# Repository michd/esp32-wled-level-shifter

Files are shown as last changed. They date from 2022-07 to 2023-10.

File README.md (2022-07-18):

# ESP32 WLED Level Shifter

A simple board to house an ESP32 dev board and a level shifter, so it can be hooked up directly to a powered 5V LED strip.

This fits a "ESP-32S Development Board", which can be found by plenty of sellers.

Designed for APA102 LEDs, so it has a CLK and DATA output.

Comes with a KiCad (6) board design and 3D-printable enclosure designed in FreeCAD.

See [Releases](https://github.com/michd/esp32-wled-level-shifter/releases) for exported PCB manufacturing files and STL files to 3D print.

## Images

The board; doesn't contain much.
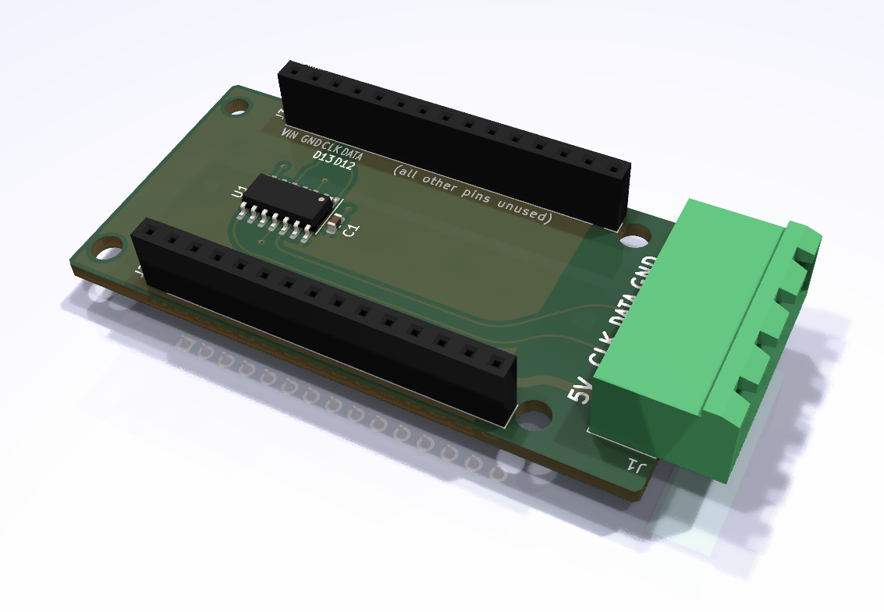
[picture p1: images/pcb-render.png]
3D render of circuit board showing generic socket pcb headers on either of the long sides, and a large 5.08mm 4 pin connector on one of the short ends


Bottom section of the 3D printed box
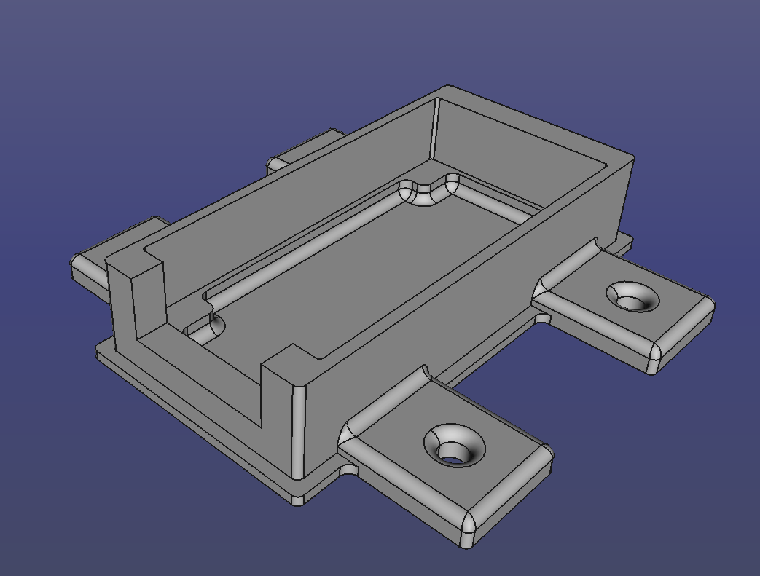
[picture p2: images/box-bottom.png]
Screenshot of FreeCAD showing the bottom of an enclosure. It's rectangular, has support for the circuit board to lay on, and a clearing in the front left wall for the connector. On both long sides, there are tabs with holes in them to fix the box to something with screws.


Top section of the 3D printed box
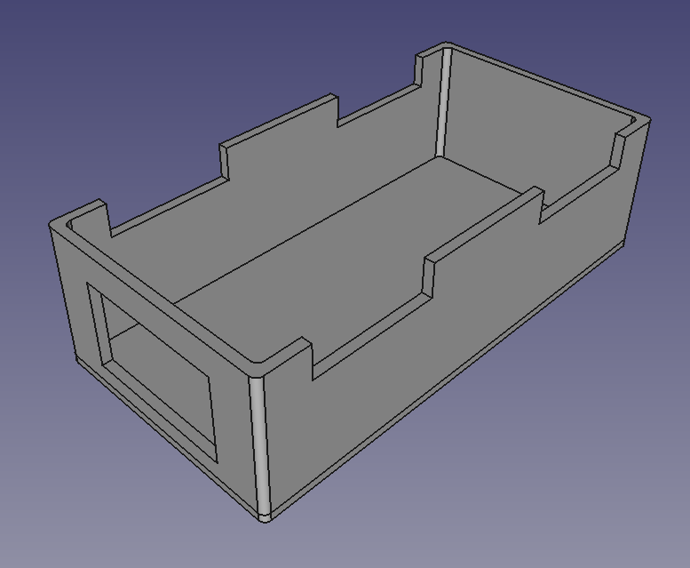
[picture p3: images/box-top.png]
Screenshot of FreeCAD showing the top of an enclosure (flipped upside down). It's rectangular with an open top, and has a clearing in the front left wall for the connector.


Assembled, in real life.
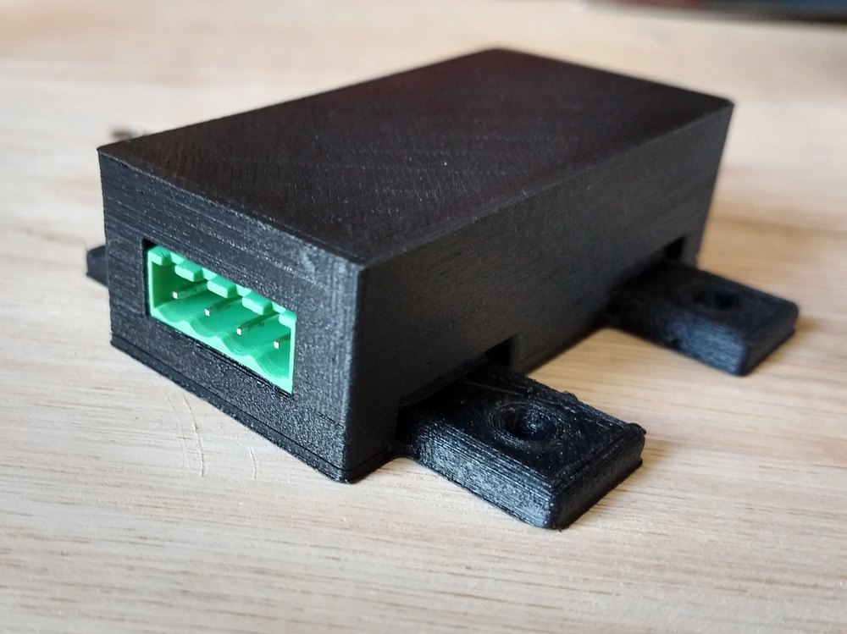
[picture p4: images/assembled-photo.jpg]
Photo of the assembled box. A black 3D printed box with the top and bottom put together (press-fit) is shown. In the clearing for the connector, you guessed it, there's the connector, flush with the edge of the enclosure.


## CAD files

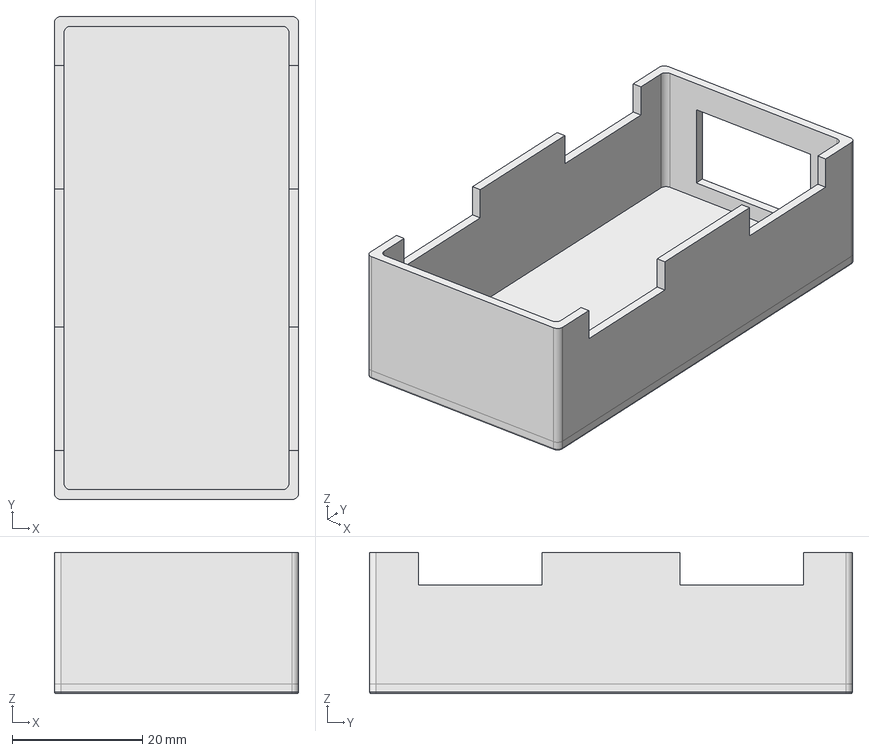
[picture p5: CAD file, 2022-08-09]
enclosure/esp32-wled-level-shifter-enclosure.FCStd
37.5 x 74.1 x 21.7 mm

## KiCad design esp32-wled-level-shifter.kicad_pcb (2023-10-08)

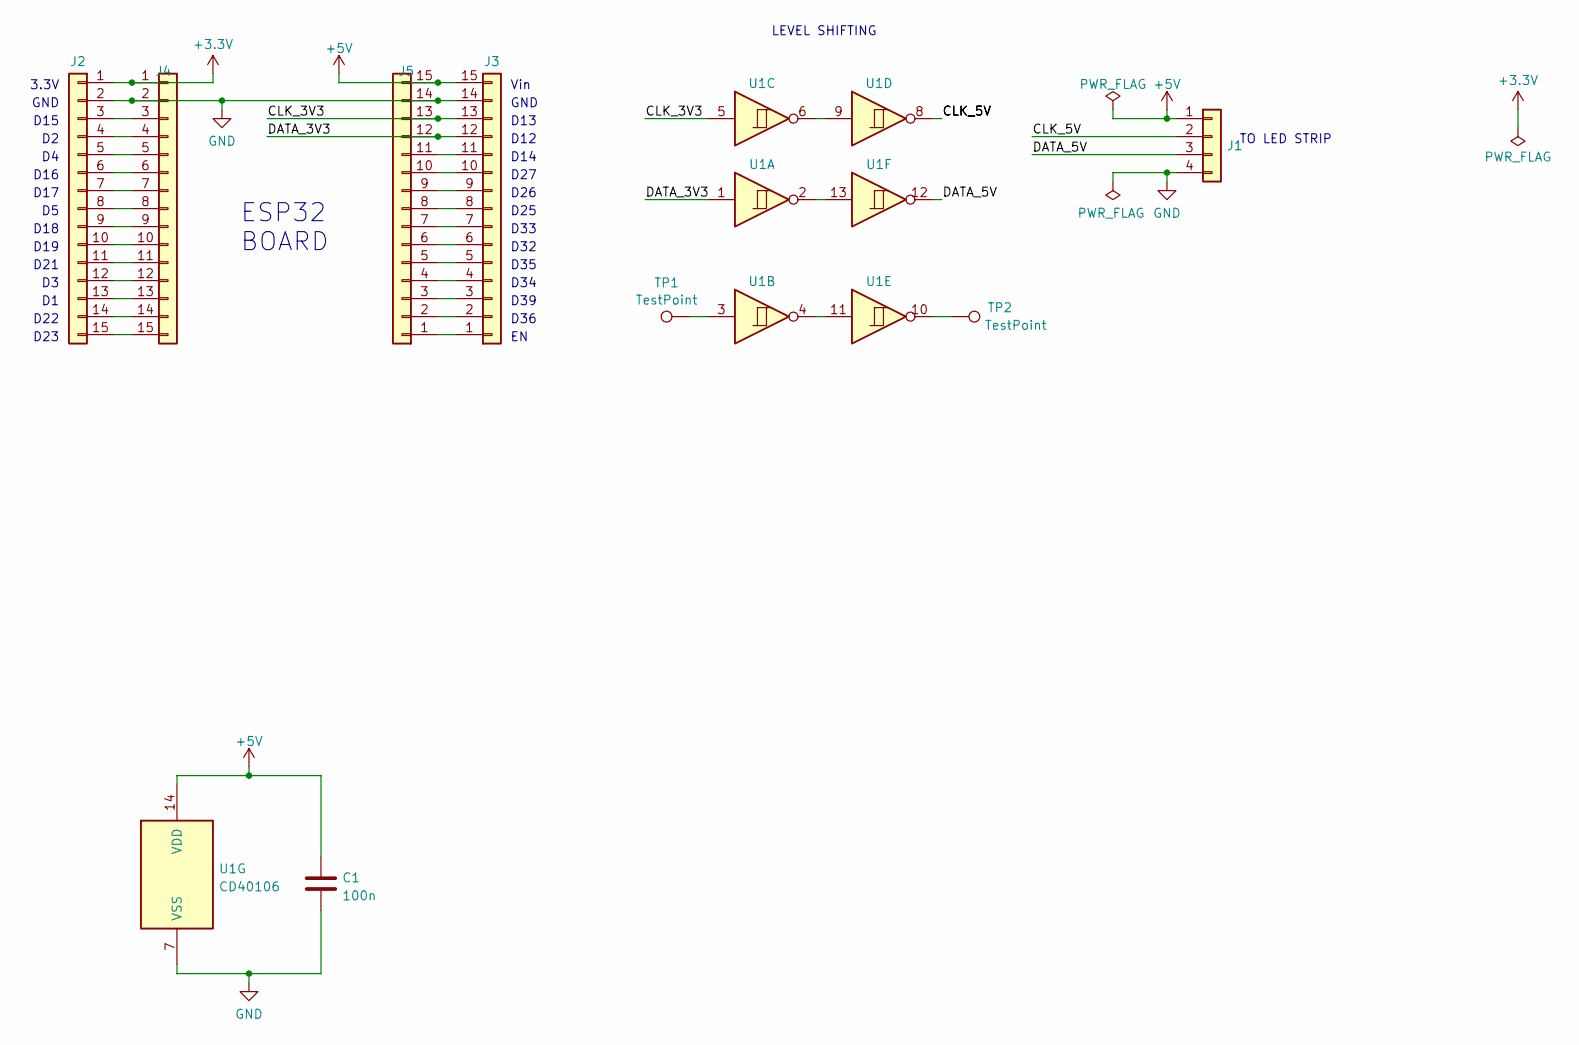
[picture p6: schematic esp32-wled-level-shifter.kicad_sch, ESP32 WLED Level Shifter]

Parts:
C1: 100n; C_0603_1608Metric; LCSC C14663
J1: Conn_01x04_Female; PhoenixContact_MSTBA_2,5_4-G-5,08_1x04_P5.08mm_Horizontal
J2, J3, J4, J5: Conn_01x15_Female; PinSocket_1x15_P2.54mm_Vertical
TP1, TP2: TestPoint; TestPoint_THTPad_D2.0mm_Drill1.0mm
U1: CD40106; SOIC-14_3.9x8.7mm_P1.27mm; LCSC C38184

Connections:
+3.3V: J2.1, J4.1
+5V: C1.1, J1.1, J3.15, J5.15, U1.14 (VDD)
/CLK_3V3: J3.13, J5.13, U1.5
/CLK_5V: J1.2, U1.8
/DATA_3V3: J3.12, J5.12, U1.1
/DATA_5V: J1.3, U1.12
GND: C1.2, J1.4, J2.2, J3.14, J4.2, J5.14, U1.7 (VSS)
unnamed: J2.3, J4.3
unnamed: J2.4, J4.4
unnamed: J2.5, J4.5
unnamed: J2.6, J4.6
unnamed: J2.7, J4.7
unnamed: J2.8, J4.8
unnamed: J2.9, J4.9
unnamed: J2.10, J4.10
unnamed: J2.11, J4.11
unnamed: J2.12, J4.12
unnamed: J2.13, J4.13
unnamed: J2.14, J4.14
unnamed: J2.15, J4.15
unnamed: J3.1, J5.1
unnamed: J3.2, J5.2
unnamed: J3.3, J5.3
unnamed: J3.4, J5.4
unnamed: J3.5, J5.5
unnamed: J3.6, J5.6
unnamed: J3.7, J5.7
unnamed: J3.8, J5.8
unnamed: J3.9, J5.9
unnamed: J3.10, J5.10
unnamed: J3.11, J5.11
unnamed: TP1.1, U1.3
unnamed: TP2.1, U1.10
unnamed: U1.6, U1.9
unnamed: U1.4, U1.11
unnamed: U1.2, U1.13

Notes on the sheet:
Vin
GND
D23
LEVEL SHIFTING
D14
D39
D13
D21
D34
D19
D15
D12
3.3V
D32
D25
D16
D26
D22
ESP32 BOARD
D33
D35
D17
D36
D18
TO LED STRIP
D27

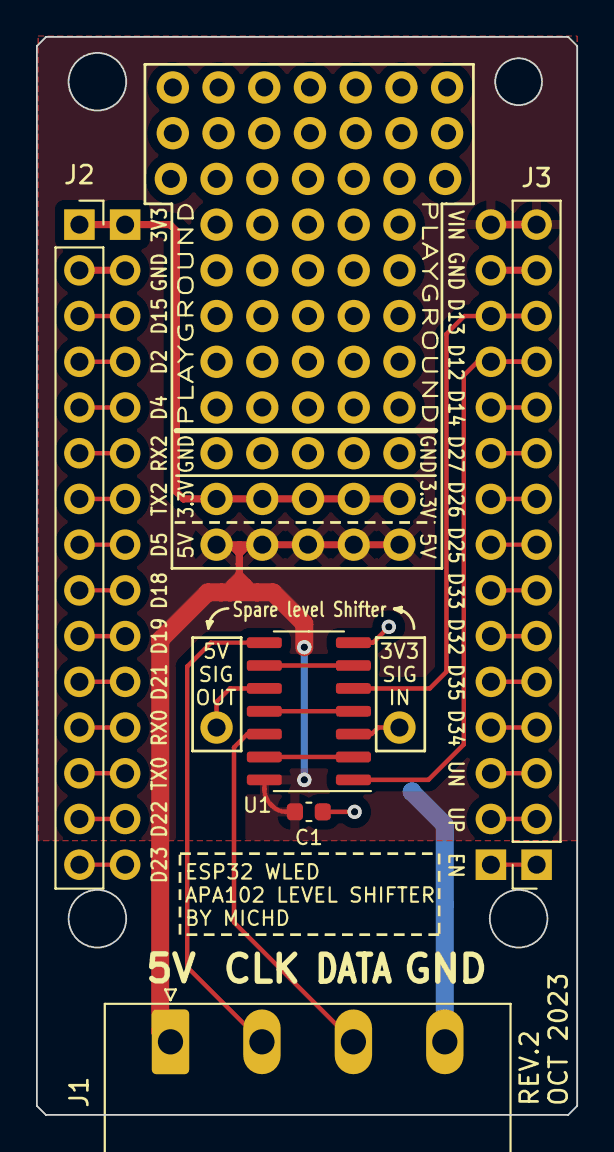
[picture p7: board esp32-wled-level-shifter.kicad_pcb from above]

Board: 2 copper layers, 30.0 x 59.9 mm, 9 parts (0 on the bottom side), 36 nets.

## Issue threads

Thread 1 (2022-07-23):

3d model of the top doesn't match the photo

beanz, 2022-07-23:
The photo appears to show the top having cutouts to permit it to sit flush to the lip on the bottom **and** allow the mount "wings" of the bottom part to stick out. However, the 3d model of the top has no such cutouts.

michd, 2022-08-09:
Thanks Mark! I've now included the changes I forgot to commit, updated the screenshot in the README, and created a new release with updated exported STLs. -> [enclosure-rev2](https://github.com/michd/esp32-wled-level-shifter/releases/tag/enclosure-rev2)

Fixed by 4d2196c90ba8f40cf075ebc1ce1ca5c4d67360cb.

Closed 2022-08-09.

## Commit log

2022-06-24 Dimension and size tweaks
    - Correctly space connectors
    - Increase size of mounting holes, allow M3
    - Chamfer board edges
    - More silkscreen markings
    [esp32-wled-level-shifter.kicad_pcb, esp32-wled-level-shifter.kicad_sch]
2022-07-08 Wip: enclosure design
    [esp32-wled-level-shifter-enclosure.FCStd]
2022-07-08 Finish top and bottom of enclosure, hopefully
    [esp32-wled-level-shifter-enclosure.FCStd]
2022-08-09 Add gaps for the screw tabs in enclosure top
    [esp32-wled-level-shifter-enclosure.FCStd]
2023-10-08 Rev2 board with experimenting playground
    [esp32-wled-level-shifter.kicad_pcb, esp32-wled-level-shifter.kicad_sch]
